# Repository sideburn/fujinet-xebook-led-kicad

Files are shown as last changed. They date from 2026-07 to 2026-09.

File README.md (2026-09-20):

# FN32ROV XEBook LED Board

A small daughter board carrying the three FujiNet status LEDs (WiFi, Bluetooth, SIO) for
the [FN32ROV-XEBook-KiCad](../FN32ROV-XEBook-KiCad) main board, which mounts the FujiNet
FN32ROV WiFi/SIO adapter permanently inside an XEBook laptop build.

On the main board, the LEDs and buttons were moved off-PCB onto JST pigtails so they can
be panel-mounted separately (see that project's `CLAUDE.md`, "External LED board
interface (J_LED1)"). This board is that panel-mounted LED daughter board.

## What's on it

- D1 (WiFi), D2 (Bluetooth), D3 (SIO) — 0402 SMD LEDs, common-anode to 3V3, each cathode
  wired back to its own signal pin. The ESP32 on the main board sinks current by driving
  the corresponding GPIO low.
  - D1 is **green** (Rohm SML-P12PTT86R) — the original FN32ROV-1.7.1 WiFi LED was white
    (SunLED XZBWR68F5MAV-3, still available); green is a deliberate choice for this build,
    not a substitution forced by availability. The main board's
    R13 was resized from 1k to 2.7k to keep the current sane for the green LED's lower
    forward voltage (~2.2V vs ~2.9V for white).
  - D2 (blue, OSRAM LB QH9G-N1OO-35-1) and D3 (orange, Rohm SML-P12DTT86R) are unchanged
    from the original FN32ROV-1.7.1 BOM.
- J1 — 4-pin JST PH vertical header, **through-hole**
  (`JST_PH_B4B-PH-K_1x04_P2.00mm_Vertical`), mounted on the **back** of the board and
  hand-soldered. An earlier revision used an SMD connector specifically to avoid THT
  pads plating through to the light-pipe side, but assembling both sides of the board
  turned out to be too costly for JLCPCB assembly — hand-soldering a THT part is cheaper.
  Since a THT part's copper unavoidably lands on both faces, J1 is instead offset well
  clear of the LED row in Y (the board's height was grown from 10mm to 14mm specifically
  to make room for this), so its pads don't land under a light pipe. Mates via a JST PH
  pigtail to J_LED1 on the main board, pin-for-pin (1=3V3, 2=LED_WIFI, 3=LED_BT,
  4=LED_SIO).

Current-limiting resistors are **not** on this board — they live on the main board
(R13/R14/R15) since this board only ever sees the LED forward voltage drop.

## Mechanical

- Board outline: 40mm x 14mm.
- LEDs sit on 10mm pitch, centered on the board (x = 10/20/30mm from the left edge,
  y = 3mm), aligned to the XEBook case's light-pipe positions. LEDs use SMD packages
  with panel light pipes carrying light out to the case surface — no hole is drilled in
  the PCB itself under each LED.
- Two M2 clearance holes (`MountingHole_2.2mm_M2`), 4mm in from each end, at y = 7mm
  (the board's vertical center) — 4mm below the LED row.
- J1's housing sits with its near edge at that same y = 7mm row (pad row at y = 9.2mm,
  2.2mm further down — that offset is baked into the connector's footprint). This gives
  the light-pipe housing (~2.1mm radius around each LED) about 1.9mm of clearance to
  J1's physical housing edge — the dimension that actually matters here, not the copper
  pad edges, since it's the plastic housings that would physically collide if this were
  too tight.
- Board thickness: 1.6mm (JLCPCB/industry standard, matches the main board).

## Status

Work in progress — schematic captured and footprints/nets placed on the PCB (ERC clean,
DRC clean, schematic/PCB parity clean). **Not yet routed** — the user routes copper by
hand in the KiCad GUI. Not yet fabricated.

## Tooling

Built with KiCad 9. `kicad-cli sch erc` / `kicad-cli pcb drc --schematic-parity` are used
to verify the design as it's built.

## License

[CERN Open Hardware Licence Version 2 - Strongly Reciprocal](LICENSE)
(CERN-OHL-S-2.0), matching the main board.

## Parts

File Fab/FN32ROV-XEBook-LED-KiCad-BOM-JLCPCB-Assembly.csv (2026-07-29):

Reference | Value | Footprint | Qty | LCSC
D1 | WIFI_LED_GREEN_0402 | LED_SMD:LED_0402_1005Metric | 1 | C471422
D2 | BT_LED_BLUE_0402 | LED_SMD:LED_0402_1005Metric | 1 | C30584803
D3 | SIO_LED_ORANGE_0402 | LED_SMD:LED_0402_1005Metric | 1 | C28310436

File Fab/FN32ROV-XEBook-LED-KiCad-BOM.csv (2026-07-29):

Reference | Value | Footprint | Qty | LCSC
D1 | WIFI_LED_GREEN_0402 | LED_SMD:LED_0402_1005Metric | 1 | C471422
D2 | BT_LED_BLUE_0402 | LED_SMD:LED_0402_1005Metric | 1 | C30584803
D3 | SIO_LED_ORANGE_0402 | LED_SMD:LED_0402_1005Metric | 1 | C28310436
J1 | LED_JST | Connector_JST:JST_PH_B4B-PH-K_1x04_P2.00mm_Vertical | 1 | C265289

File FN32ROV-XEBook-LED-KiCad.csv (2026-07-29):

Id | Designator | Footprint | Quantity | Designation | Supplier and ref
1 | D2 | LED_0402_1005Metric | 1 | BT_LED_BLUE_0402
2 | D1 | LED_0402_1005Metric | 1 | WIFI_LED_GREEN_0402
3 | D3 | LED_0402_1005Metric | 1 | SIO_LED_ORANGE_0402
4 | J1 | JST_PH_B4B-PH-SM4-TB_1x04-1MP_P2.00mm_Vertical | 1 | LED_JST

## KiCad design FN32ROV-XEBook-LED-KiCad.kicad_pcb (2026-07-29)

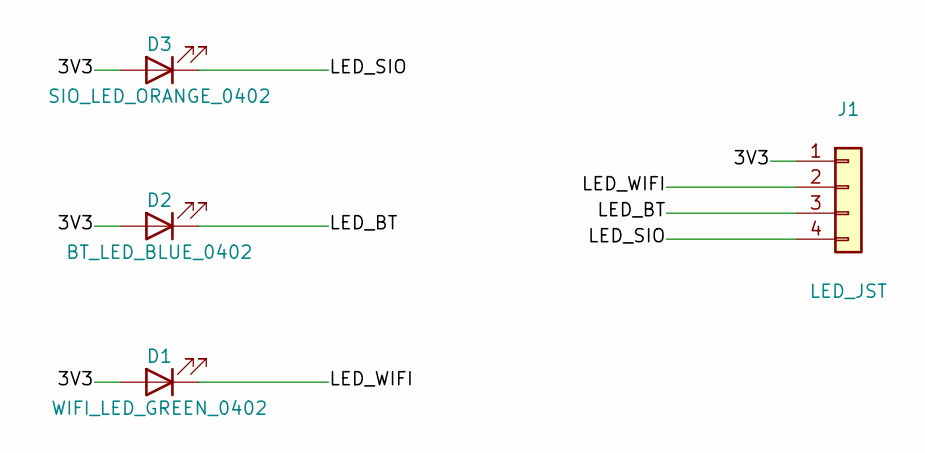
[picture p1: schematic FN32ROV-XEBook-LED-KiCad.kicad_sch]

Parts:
D1: WIFI_LED_GREEN_0402; LED_0402_1005Metric; LCSC C471422
D2: BT_LED_BLUE_0402; LED_0402_1005Metric; LCSC C30584803
D3: SIO_LED_ORANGE_0402; LED_0402_1005Metric; LCSC C28310436
J1: LED_JST; JST_PH_B4B-PH-K_1x04_P2.00mm_Vertical; LCSC C265289

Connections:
/3V3: D1.2 (A), D2.2 (A), D3.2 (A), J1.1
/LED_BT: D2.1 (K), J1.3
/LED_SIO: D3.1 (K), J1.4
/LED_WIFI: D1.1 (K), J1.2

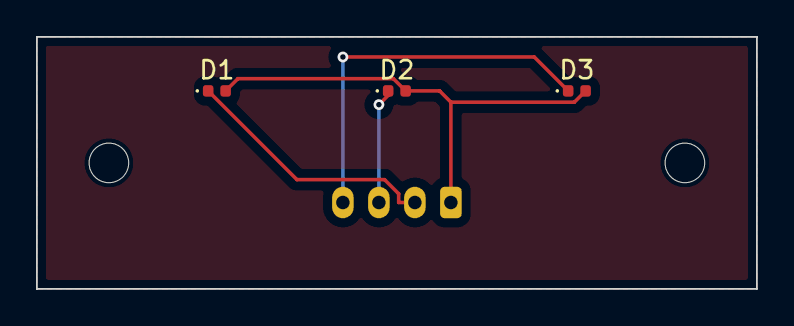
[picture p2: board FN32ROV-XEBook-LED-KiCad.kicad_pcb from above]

Board: 2 copper layers, 40.0 x 14.0 mm, 6 parts (1 on the bottom side), 4 nets.

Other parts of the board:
MH1, MH2: MountingHole_2.2mm_M2

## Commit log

2026-07-29 Initial LED daughter board: schematic, routed PCB, and fab output
    Three status LEDs (WiFi green, Bluetooth blue, SIO orange) common-anode to
    3V3, each cathode returning through its own JST PH pin to J_LED1 on the
    FN32ROV-XEBook-KiCad main board. J1 is SMD (not through-hole) so its copper
    never plates through to the light-pipe side of the board. Board is 40mm x
    10mm with two M2 mounting holes, sized and positioned to match the XEBook
    case light-pipe hole spacing.
    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
    [FN32ROV-XEBook-LED-KiCad-B_Cu.gbr, FN32ROV-XEBook-LED-KiCad-B_Mask.gbr, FN32ROV-XEBook-LED-KiCad-B_Paste.gbr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]
2026-07-29 Switch J1 back to through-hole, grow board to 40x14mm, add logo, export fab files
    Assembling both sides (SMD LEDs on front + SMD JST on back) was too costly for
    JLCPCB assembly, so J1 reverts to through-hole and gets hand-soldered instead.
    That meant reworking the board height and LED/connector Y-offsets so the
    through-hole housing does not physically collide with the case light-pipe
    housings (the earlier SMD-based clearance math did not carry over, since THT
    housings are much deeper than the SMD footprint was).
    Board is now 40x14mm: LEDs at y=3mm, mounting holes + J1 housing edge on the
    y=7mm row, J1 pad row at y=9.2mm. Logo centered exactly on the back silkscreen.
    LCSC part numbers record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
    [FN32ROV-XEBook-LED-KiCad-BOM-JLCPCB-Assembly.csv, FN32ROV-XEBook-LED-KiCad-BOM.csv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]
2026-08-02 Record shipped status and why the floating pour is correct here
    Rev 1.0 was fabricated at JLCPCB (not PCBWay) and has shipped. Unlike the main
    and SD boards, this one needed no revision: the 2026-07-31 audit's floating-pour
    finding does not apply, because the circuit is common-anode 3V3 plus three
    cathode signals and has no GND net to tie the pour to. Documented so it is not
    "fixed" later by tying the pour to 3V3.
    Fab/ therefore stays flat -- no as-built archive, no 1.1 package -- since it
    still matches source exactly.
    Claude-Session: https://claude.ai/code/session_01VRTanwY2PaFNJQ1vUGmami
2026-09-20 Record the brightness match: fix is R14/R15 on the main board
    D2 (blue) and D3 (orange) read about twice as bright as D1 (green) on the
    first build. D1 is the reference, so the main board's R14 goes 1k -> 30k and
    R15 1.2k -> 10K (R13 stays 2.7k), found by a bench match with this board
    powered at 3.33V. Nothing changes on this board.
    Also clarifies in the README that green D1 is a deliberate choice -- the
    original white SunLED part is still available, not obsolete.
2026-10-16 Silkscreen: add pin-1 marker to J1
    Marks pin 1 on the cable header so the harness to the main board cannot
    be seated backwards during assembly.
    Verified against the previous commit: footprints, pads, copper segments,
    vias and zone definitions are all unchanged. Only F.SilkS text was added
    (plus zone refills and uuid churn from the save).
2026-10-16 Regenerate fab package for the next order
    Re-exported with kicad-cli 9.0.7 to pick up the new pin-1 / connector
    silkscreen. Versioned filenames rather than overwriting the previous
    package, so the wrong zip cannot be uploaded by mistake.
    Copper, paste, mask, drill and outline unchanged; BOM and CPL carried
    over byte-identical since no component moved. See CLAUDE.md for the
    per-board detail.
